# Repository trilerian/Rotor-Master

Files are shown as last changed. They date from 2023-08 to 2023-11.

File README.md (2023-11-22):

# Rotor-Master

I have uploaded new Gerbers that have components to put a small load on the output of the sensors.  Also changed the reset resistor to an smb type. 
Need to add the parts to the BOM still
Adds 3 4.7nf 0805 smb capacitors
Adds 4 10k 0805 smb resistors
09/11/2023 - BOM update.  BOM.xlsx is the bom you should use

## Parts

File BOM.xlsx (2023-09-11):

BOM |  | Parts I used |  | QTY | Mouser, Amazon, McMaster-Carr
Name | Comment | Part# | Price
ATmega328P | Microcontroller | ATMEGA328P-PU | $2.97 | x1 | https://www.mouser.com/ProductDetail/Microchip-Technology/ATMEGA328P-PU?qs=K8BHR703ZXguOQv3sKbWcg%3D%3D
MCP3208 | 12bit ADC | MCP3208-CI/P | $4.97 | x1 | https://www.mouser.com/ProductDetail/579-MCP3208CIP
MCP3208 Optional | More Accurate | MCP3208-BI/P | $6.21 |  | https://www.mouser.com/ProductDetail/Microchip-Technology/MCP3208-BI-P?qs=iwvYsH9bSFbUibDxw9o3cw%3D%3D
L7805 | 5v volltage regulator | L7805CV | $0.69 | x1 | https://www.mouser.com/ProductDetail/STMicroelectronics/L7805CV?qs=9NrABl3fj%2FqplZAHiYUxWg%3D%3D
A1308 | Hall effect senosr, 1.3mv/G | A1308LLHLX-1-T | $1.83 | x3 | https://www.mouser.com/ProductDetail/250-A1308LLHLX-1-T
Capacitor | MLCC SMD 100nf | C1206C104K5RAC7867 | $0.11 | x3 | https://www.mouser.com/ProductDetail/80-C1206104K5RAC7867
Capacitor | MLCC SMD 330nf | C1206C334K5RACTU | $0.18 | x1 | https://www.mouser.com/ProductDetail/80-C1206C334K5R
Capacitor | MLCC SMD 22pf | C1206C220K5HACTU | $0.17 | x2 | https://www.mouser.com/ProductDetail/80-C1206C220K5HACTU
Capacitor | MLCC SMD 1uf | C1206C105K5RACTU | $0.27 | x1 | https://www.mouser.com/ProductDetail/80-C1206C105K5R
Capacitor | MLCC SMD 4700pf | C0805C472K5RACAUTO | $0.12 | x3 | https://www.mouser.com/ProductDetail/80-C0805C472K5RAUTO
Capacitor | Tantalum SMD 10uf | T491B106K016ATAUTO | $0.54 | x2 | https://www.mouser.com/ProductDetail/80-T491B106K016AUTO
Push Button Switch |  | FSM6JH | $0.16 | x1 | https://www.mouser.com/ProductDetail/506-FSM6JH
16 Mhz Crystal |  | LFXTAL013224Bulk | $0.50 | x1 | https://www.mouser.com/ProductDetail/449-LFXTAL013224BULK
Resistor, thick film | 10k | RC0805FR-0710KL | $0.10 | x4 | https://www.mouser.com/ProductDetail/603-RC0805FR-0710KL
Pin Header | 2.54 spacing, you will get a lot extra… |  | 5.49/8 | x1 | https://www.amazon.com/HiLetgo-20pcs-2-54mm-Single-Header/dp/B07R5QDL8D
JST XH connector | I use the male with pigtails, again, you will get extras |  | 8.79/20 | x1 | https://www.amazon.com/gp/product/B06XXZJH61/ref=ppx_yo_dt_b_search_asin_title?ie=UTF8&psc=1
0.96" oled screen | Comes in a 5 pack |  | 14.99/5 | x1 | https://www.amazon.com/gp/product/B09C5K91H7/ref=ppx_yo_dt_b_search_asin_title?ie=UTF8&th=1
M3x6 btn head screw |  |  | 9.37/100 | x4 | https://www.mcmaster.com/catalog/129/3382/91239A111
m2x5 btn head screw |  |  | $9.69/50 | x4
m3x6 flat head screw |  |  | $5.82/100 | x4
3d Printed Case | Cost in pla |  | $2.00 | x1
PCB | Min order from JLCPCB is 5, remove order number, and confirm production file |  | 25.10/5 | x1
XT60 Connector |  |  | $2.20 | x5 | https://www.amazon.com/Female-Bullet-Connectors-Sheath-Connector/dp/B0CB1JNC9Z?s=electronics
16awg wire 12" |  |  | $2.00 | x1
The below is not needed for the unit, but needed to put it together
Aruino Uno if you don't have one | You will need this to burn the boot loader and program the mcu |  | $14.44 | x1 | https://www.amazon.com/ELEGOO-Board-ATmega328P-ATMEGA16U2-Compliant/dp/B01EWOE0UU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
Bread board, any will do
male to female jumpers
22pf ceramic tht capacitors x2
male to male jumpers

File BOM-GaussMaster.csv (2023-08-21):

Comment | Designator | Footprint | LCSC
GND | J2 | SolderPad_5x5
POS | J1 | SolderPad_5x5
100nf | C4 | C_1206_3216Metric_Pad1.33x1.80mm_HandSolder
I2C | J4 | JST_XH_B4B-XH-A_1x04_P2.50mm_Vertical
M3 | H3 | MountingHole_3.2mm_M3
M3 | H2 | MountingHole_3.2mm_M3
ATmega328P-P | U1 | DIP-28_W7.62mm
SW_Push_Dual | SW1 | SW_PUSH_6mm_H7.3mm
16MHz | Y1 | Crystal_HC49-4H_Vertical
100nf | C2 | C_1206_3216Metric_Pad1.33x1.80mm_HandSolder
M3 | H1 | MountingHole_3.2mm_M3
10uf | C3 | CP_EIA-3528-21_Kemet-B_Pad1.50x2.35mm_HandSolder
1308 | U4 | SOT-23W
1uf | C8 | C_1206_3216Metric_Pad1.33x1.80mm_HandSolder
MCP3208 | U3 | DIP-16_W7.62mm
1308 | U5 | SOT-23W
22pf | C7 | C_1206_3216Metric_Pad1.33x1.80mm_HandSolder
22pf | C6 | C_1206_3216Metric_Pad1.33x1.80mm_HandSolder
10uf | C9 | CP_EIA-3528-21_Kemet-B_Pad1.50x2.35mm_HandSolder
L7805 | U2 | TO-220-3_Horizontal_TabDown
1308 | U6 | SOT-23W
100nf | C5 | C_1206_3216Metric_Pad1.33x1.80mm_HandSolder
330nf | C1 | C_1206_3216Metric_Pad1.33x1.80mm_HandSolder
PGM | J3 | PinHeader_1x05_P2.54mm_Vertical
10k | R1 | R_Axial_DIN0207_L6.3mm_D2.5mm_P7.62mm_Horizontal
M3 | H4 | MountingHole_3.2mm_M3

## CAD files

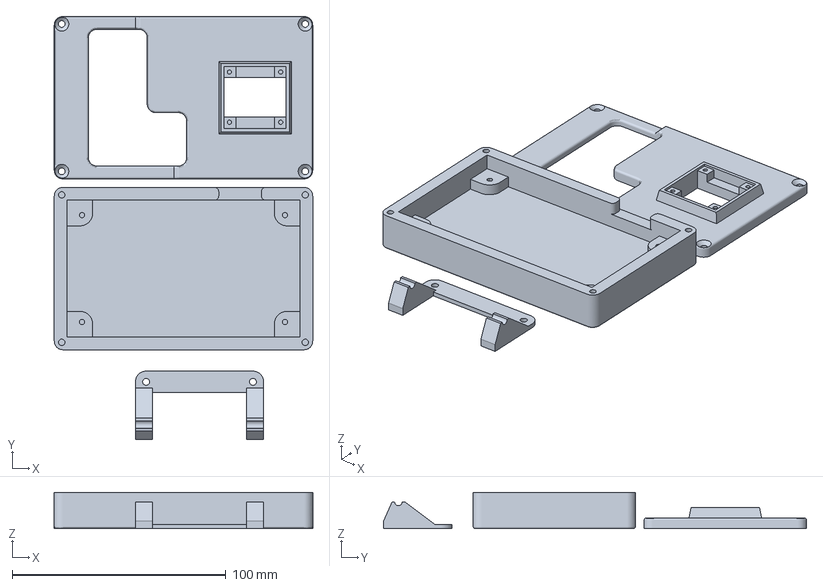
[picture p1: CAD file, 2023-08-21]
Rotor-Master v18.3mf
121.0 x 198.0 x 17.0 mm

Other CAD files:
Rotor-Master v18.f3d
Rotor-Master v18.stl

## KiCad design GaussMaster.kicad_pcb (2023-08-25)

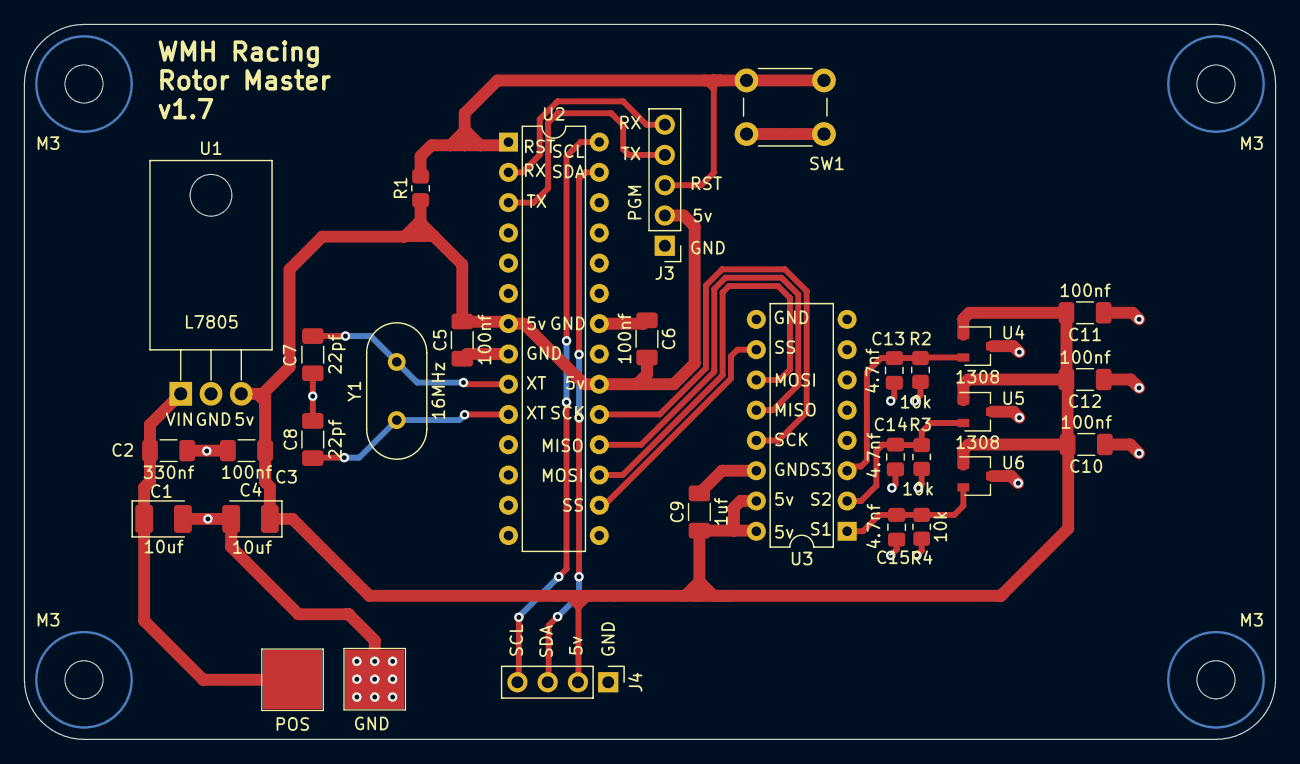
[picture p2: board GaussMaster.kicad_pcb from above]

Board: 2 copper layers, 105.0 x 60.0 mm, 35 parts (0 on the bottom side), 17 nets.

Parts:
C1, C4: 10uf; CP_EIA-3528-21_Kemet-B_Pad1.50x2.35mm_HandSolder
C2: 330nf; C_1206_3216Metric_Pad1.33x1.80mm_HandSolder
C3, C5, C6, C10, C11, C12: 100nf; C_1206_3216Metric_Pad1.33x1.80mm_HandSolder
C7, C8: 22pf; C_1206_3216Metric_Pad1.33x1.80mm_HandSolder
C9: 1uf; C_1206_3216Metric_Pad1.33x1.80mm_HandSolder
C13, C14, C15: 4.7nf; C_0805_2012Metric_Pad1.18x1.45mm_HandSolder
H1, H2, H3, H4: M3; MountingHole_3.2mm_M3
J1: POS; SolderPad_5x5
J2: GND; SolderPad_5x5
J3: PGM; PinHeader_1x05_P2.54mm_Vertical
J4: I2C; PinHeader_1x04_P2.54mm_Vertical
R1, R2, R3, R4: 10k; R_0805_2012Metric_Pad1.20x1.40mm_HandSolder
SW1: SW_Push_Dual; SW_PUSH_6mm_H7.3mm
U1: L7805; TO-220-3_Horizontal_TabDown
U2: ATmega328P-P; DIP-28_W7.62mm
U3: MCP3208; DIP-16_W7.62mm
U4, U5, U6: 1308; SOT-23W
Y1: 16MHz; Crystal_HC49-4H_Vertical

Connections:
/+5v: C3.1, C4.1, C5.2, C6.2, C9.1, C10.2, C11.2, C12.2, J3.2, J4.2, R1.1, U1.3 (OUT), U2.7 (VCC), U2.20 (AVCC), U3.15 (Vref), U3.16 (Vdd), U4.1 (VCC), U5.1 (VCC), U6.1 (VCC)
/+8.4v: C1.1, C2.1, J1.1, U1.1 (IN)
/MISO: U2.18 (PB4), U3.12 (Dout)
/MOSI: U2.17 (PB3), U3.11 (Din)
/RESET: J3.3, R1.2, SW1.2, U2.1 (~RESET/PC6)
/RX: J3.5, U2.2 (PD0)
/SCK: U2.19 (PB5), U3.13 (CLK)
/SCL: J4.4, U2.28 (PC5)
/SDA: J4.3, U2.27 (PC4)
/SS: U2.16 (PB2), U3.10 (~CS/SHDN)
/TX: J3.4, U2.3 (PD1)
/XTAL1: C7.1, U2.9 (XTAL1/PB6), Y1.2
/XTAL2: C8.1, U2.10 (XTAL2/PB7), Y1.1
GND: C1.2, C2.2, C3.2, C4.2, C5.1, C6.1, C7.2, C8.2, C9.2, C10.1, C11.1, C12.1, C13.2, C14.2, C15.2, J2.1, J3.1, J4.1, R2.2, R3.2, R4.2, SW1.1, U1.2 (GND), U2.8 (GND), U2.22 (GND), U3.9 (DGND), U3.14 (AGND), U4.3 (GND), U5.3 (GND), U6.3 (GND)
SEN1: C15.1, R4.1, U3.1 (CH0), U6.2 (VOUT)
SEN2: C14.1, R3.1, U3.2 (CH1), U5.2 (VOUT)
SEN3: C13.1, R2.1, U3.3 (CH2), U4.2 (VOUT)

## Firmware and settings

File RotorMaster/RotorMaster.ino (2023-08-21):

/* Rotor Master v1.1
A WHM Racing product
written by Andrew Sarratore
Date: 7/31/2023
*/



#include <Wire.h>
#include <Adafruit_GFX.h>
#include <Adafruit_SSD1306.h>

#define SCREEN_WIDTH 128 // OLED display width, in pixels
#define SCREEN_HEIGHT 64 // OLED display height, in pixels
#define SELPIN 10 //Selection Pin 
#define DATAOUT 11//MOSI 
#define DATAIN  12//MISO 
#define SPICLOCK  13//Clock 


// Declaration for an SSD1306 display connected to I2C (SDA, SCL pins)
Adafruit_SSD1306 display(SCREEN_WIDTH, SCREEN_HEIGHT, &Wire, -1);


float VCC = 5.0000; // Arduino Voltage
float QOV1 = 2.5000;  // Quiescent Output Sensor1
float QOV2 = 2.5000;  // Quiescent Output Sensor2
float QOV3 = 2.5000;  // Quiescent Output Sensor3
float M1 = -1.0000; // Multiplier Sen1
float M2 = -1.0000; // Multiplier Sen2
float M3 = -1.0000; // Multiplier Sen3
int Offset1 = 2048; // Set raw reading to 0
int Offset2 = 2048; // Set raw reading to 0
int Offset3 = 2048; // Set raw reading to 0
float Sensitivity = 0.0013;
int DEL=2000;
float divider = (4095 / VCC); // Compensate for Voltage difference of 5v
int readvalue1; //Raw read from ADC1
int readvalue2; //Raw read from ADC2
int readvalue3; //Raw read from ADC3
int Zero1; // Zero the reading for calculations, allows for +/-
int Zero2; // Zero the reading for calculations, allows for +/-
int Zero3; // Zero the reading for calculations, allows for +/-
int Gauss1; //Calculated Gauss
int Gauss2; //Calculated Gauss
int Gauss3; //Calculated Gauss
int HighGauss1=0; //Variable for Max + Value
int HighGauss2=0; //Variable for Max + Value
int HighGauss3=0; //Variable for Max + Value
int LowGauss1=0; //Variable for Max - Value
int LowGauss2=0; //Variable for Max - Value
int LowGauss3=0; //Variable for Max - Value
float Voltage1; // Voltage of Zero
float Voltage2; // Voltage of Zero
float Voltage3; // Voltage of Zero
float G1; // Gauss before Multiplier
float G2; // Gauss before Multiplier
float G3; // Gauss before Multiplier
float OffsetV1;
float OffsetV2;
float OffsetV3;



void setup() {
  Serial.begin(9600);
   if(!display.begin(SSD1306_SWITCHCAPVCC, 0x3C)) { // Address 0x3D for 128x64
    Serial.println(F("SSD1306 allocation failed"));
    }
  delay(1000);
  display.clearDisplay();
  display.setTextSize(2);
  display.setTextColor(WHITE);
  display.setCursor(0,0);
  display.println("WMH Racing");
  display.setCursor(0,16);
  display.println("Where the");
  display.setCursor(0,32);
  display.println("Magic");
  display.setCursor(0,48);
  display.println("HAPPENS!!");
  display.display(); 
  pinMode(SELPIN, OUTPUT); 
  pinMode(DATAOUT, OUTPUT); 
  pinMode(DATAIN, INPUT); 
  pinMode(SPICLOCK, OUTPUT); 
  digitalWrite(SELPIN,HIGH); 
  digitalWrite(DATAOUT,LOW); 
  digitalWrite(SPICLOCK,LOW); 
  delay(2000);

}


int read_adc(int channel){
  int adcvalue = 0;
  byte commandbits = B11000000; //command bits - start, mode, chn (3), dont care (3)

  //allow channel selection
  commandbits|=((channel-1)<<3);

  digitalWrite(SELPIN,LOW); //Select adc
  // setup bits to be written
  for (int i=7; i>=3; i--){
    digitalWrite(DATAOUT,commandbits&1<<i);
    //cycle clock
    digitalWrite(SPICLOCK,HIGH);
    digitalWrite(SPICLOCK,LOW);    
  }

  digitalWrite(SPICLOCK,HIGH);    //ignores 2 null bits
  digitalWrite(SPICLOCK,LOW);
  digitalWrite(SPICLOCK,HIGH);  
  digitalWrite(SPICLOCK,LOW);

  //read bits from adc
  for (int i=11; i>=0; i--){
    adcvalue+=digitalRead(DATAIN)<<i;
    //cycle clock
    digitalWrite(SPICLOCK,HIGH);
    digitalWrite(SPICLOCK,LOW);
  }
  digitalWrite(SELPIN, HIGH); //turn off device
  return adcvalue;
}


void loop() {
readvalue1 = read_adc(1); 
readvalue2 = read_adc(2);
readvalue3 = read_adc(3); 
OffsetV1 = (Offset1 - (QOV1 * divider)) / divider; 
OffsetV2 = (Offset2 - (QOV2 * divider)) / divider;
OffsetV3 = (Offset3 - (QOV3 * divider)) / divider;
Voltage1 = (readvalue1) / divider;
Voltage2 = (readvalue2) / divider;
Voltage3 = (readvalue3) / divider;
Zero1 = readvalue1 - Offset1;
Zero2 = readvalue2 - Offset2;
Zero3 = readvalue3 - Offset3;
G1 = ((Voltage1 - OffsetV1)-QOV1) / Sensitivity;
G2 = ((Voltage2 - OffsetV2)-QOV2) / Sensitivity;
G3 = ((Voltage3 - OffsetV3)-QOV3) / Sensitivity;
Gauss1 = G1 * M1;
Gauss2 = G2 * M2;
Gauss3 = G3 * M3;
if (Gauss1 > HighGauss1) HighGauss1 = Gauss1;
if (Gauss2 > HighGauss2) HighGauss2 = Gauss2;
if (Gauss3 > HighGauss3) HighGauss3 = Gauss3;
if (Gauss1 < LowGauss1) LowGauss1 = Gauss1;
if (Gauss2 < LowGauss2) LowGauss2 = Gauss2;
if (Gauss3 < LowGauss3) LowGauss3 = Gauss3;


  display.clearDisplay();
  display.setTextSize(2);
  display.setTextColor(WHITE);
  display.setCursor(0,0);
  display.println("WMH Racing");
  display.setCursor(0,16);
  if ((Gauss1 <= 10) && (Gauss1 >= -10)) {
    display.println("0");
  } 
    else
    {
    display.println(Gauss1);
    }

  display.setCursor(64,16);
  if (Gauss1 >= 0) 
   {
      display.print(HighGauss1);
   }
     else
     {
       display.print(LowGauss1);
     }

  display.setCursor(0,32);
  if ((Gauss2 <= 10) && (Gauss2 >= -10)) {
  display.println("0");
  } 
    else
    {
    display.println(Gauss2);
    }

  display.setCursor(64,32);
  if (Gauss2 >= 0) 
    {
     display.print(HighGauss2);
   }
    else
    {
       display.print(LowGauss2);
    }

  display.setCursor(0,48);
  if ((Gauss3 <= 10) && (Gauss3 >= -10)) {
    display.println("0");
  } 
    else
    {
    display.println(Gauss3);
    }

  display.setCursor(64,48);
  if (Gauss3 >= 0) 
    {
      display.print(HighGauss3);
    }
      else
      {
        display.print(LowGauss3);
      }

  display.display();
  
 
 
 Serial.print(readvalue1,DEC); 
 Serial.print(" RV1 ");
 Serial.print((Voltage1),3);
 Serial.print(" V1 ");
 Serial.print(Zero1);
 Serial.print(" ZERO1 ");
 Serial.print(G1);
 Serial.print(" 1st ");
 Serial.print(Gauss1);
 Serial.print(" Gauss1");
 Serial.println();
 Serial.print(readvalue2,DEC); 
 Serial.print(" RV2 ");
 Serial.print((Voltage2),3);
 Serial.print(" V2 ");
 Serial.print(Zero2);
 Serial.print(" ZERO2 ");
 Serial.print(G2);
 Serial.print(" 2nd ");
 Serial.print(Gauss2);
 Serial.print(" Gauss2");
 Serial.println(" "); 
 Serial.print(readvalue3,DEC); 
 Serial.print(" RV3 ");
 Serial.print((Voltage3),3);
 Serial.print(" V3 ");
 Serial.print(Zero3);
 Serial.print(" ZERO3 ");
 Serial.print(G3);
 Serial.print(" 3rd ");
 Serial.print(Gauss3);
 Serial.print(" Gauss3");
 Serial.println(" "); 
 

delay(DEL);

 
}
